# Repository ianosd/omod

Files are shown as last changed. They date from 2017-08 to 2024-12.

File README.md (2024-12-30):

# omod - Open Source Motor Driver
A motor driver used to command two motors. It avoids the complications of an H-bridge
by using a relay to switch the command direction (at the cost of making switching slower).
Checkout [the schematic pdf](schematic.pdf) for a quick impression.
You need KiCad to open the project files.

Here is a picture of the PCB layout:
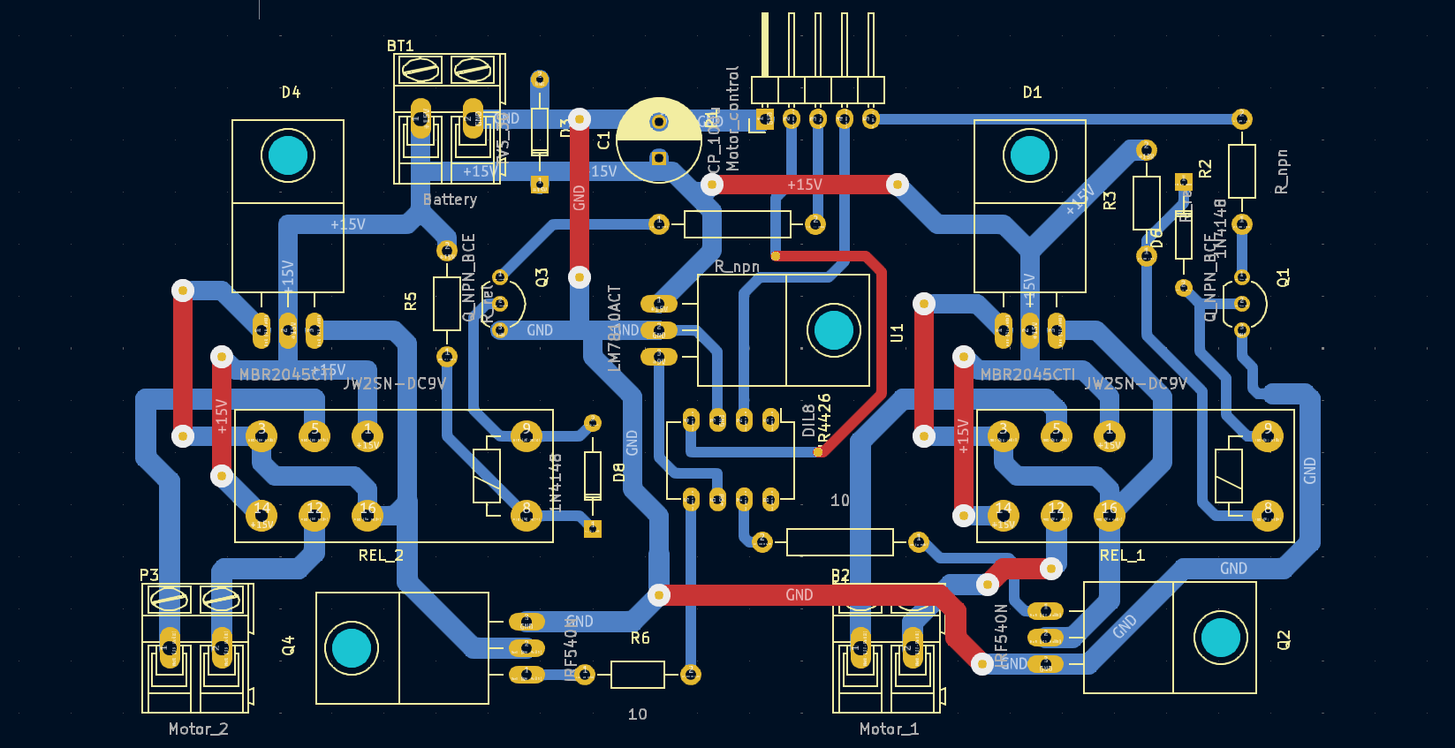
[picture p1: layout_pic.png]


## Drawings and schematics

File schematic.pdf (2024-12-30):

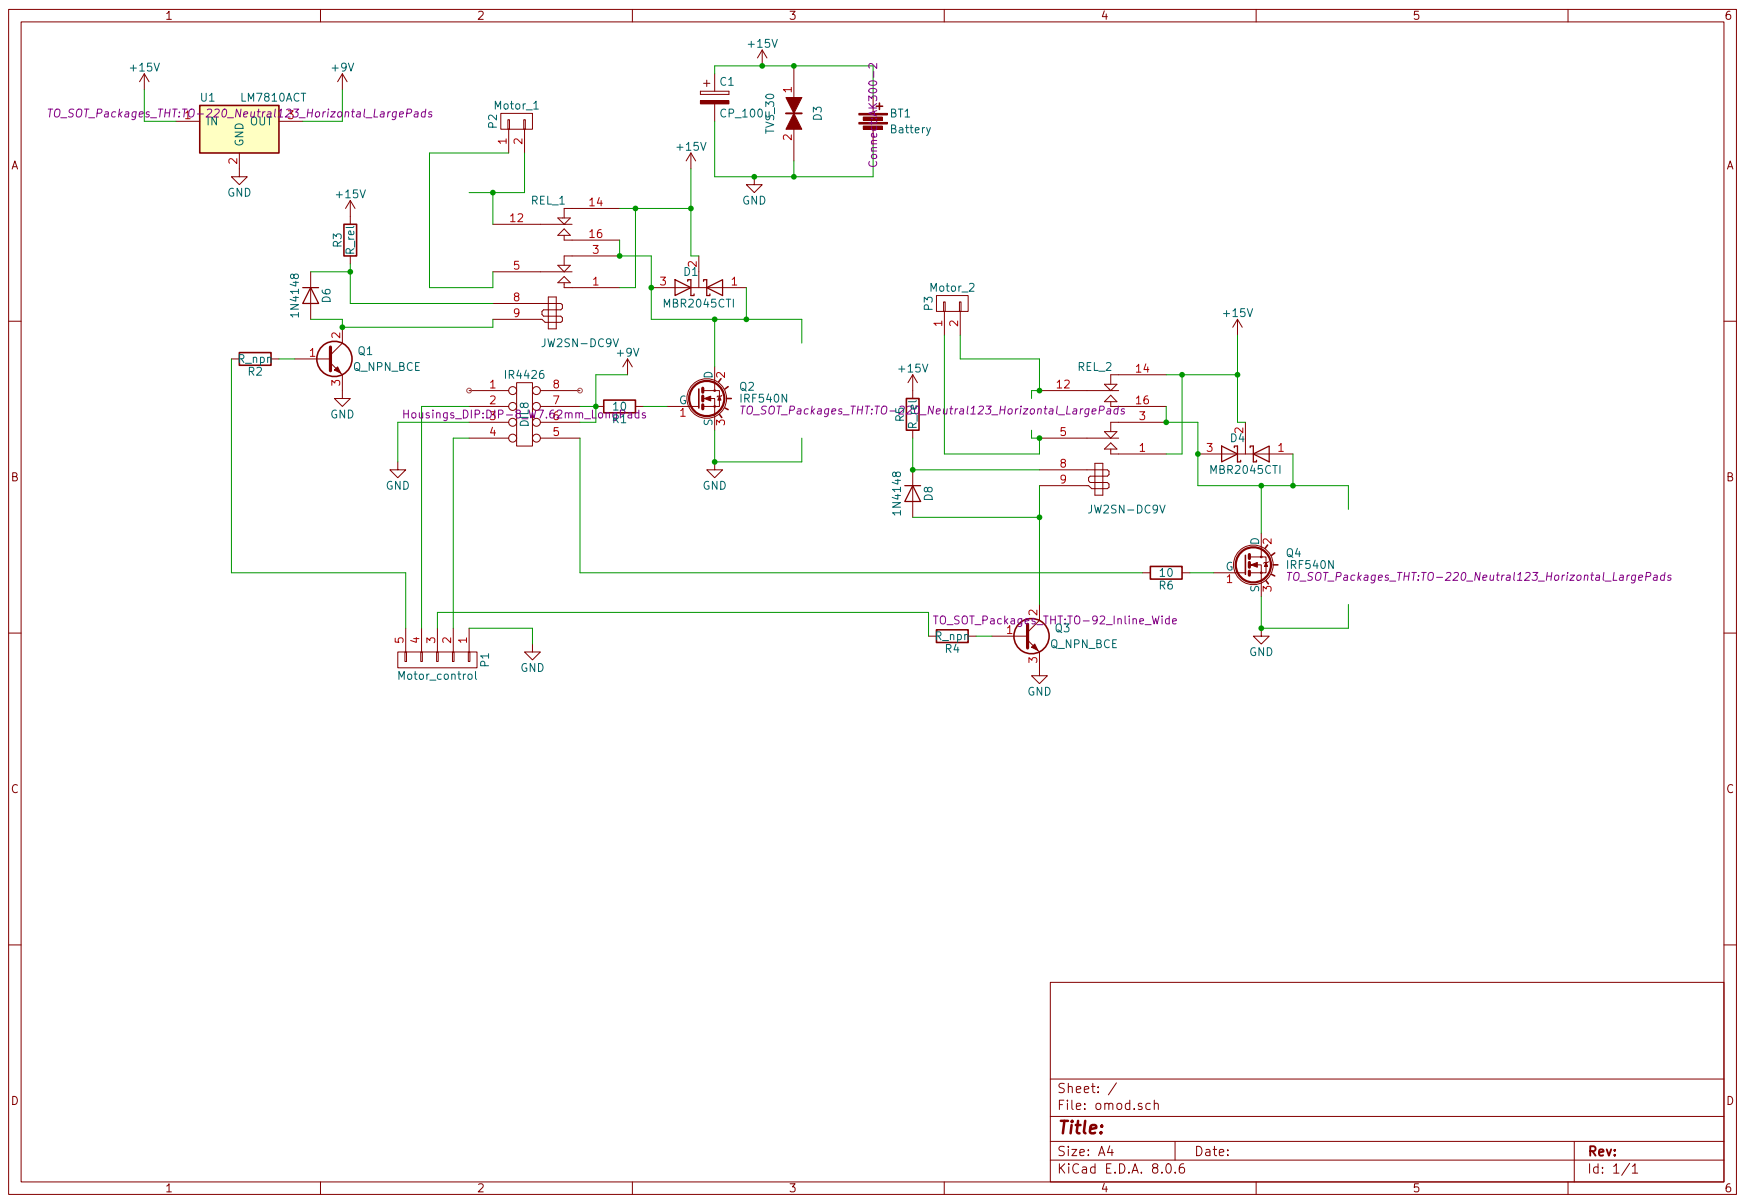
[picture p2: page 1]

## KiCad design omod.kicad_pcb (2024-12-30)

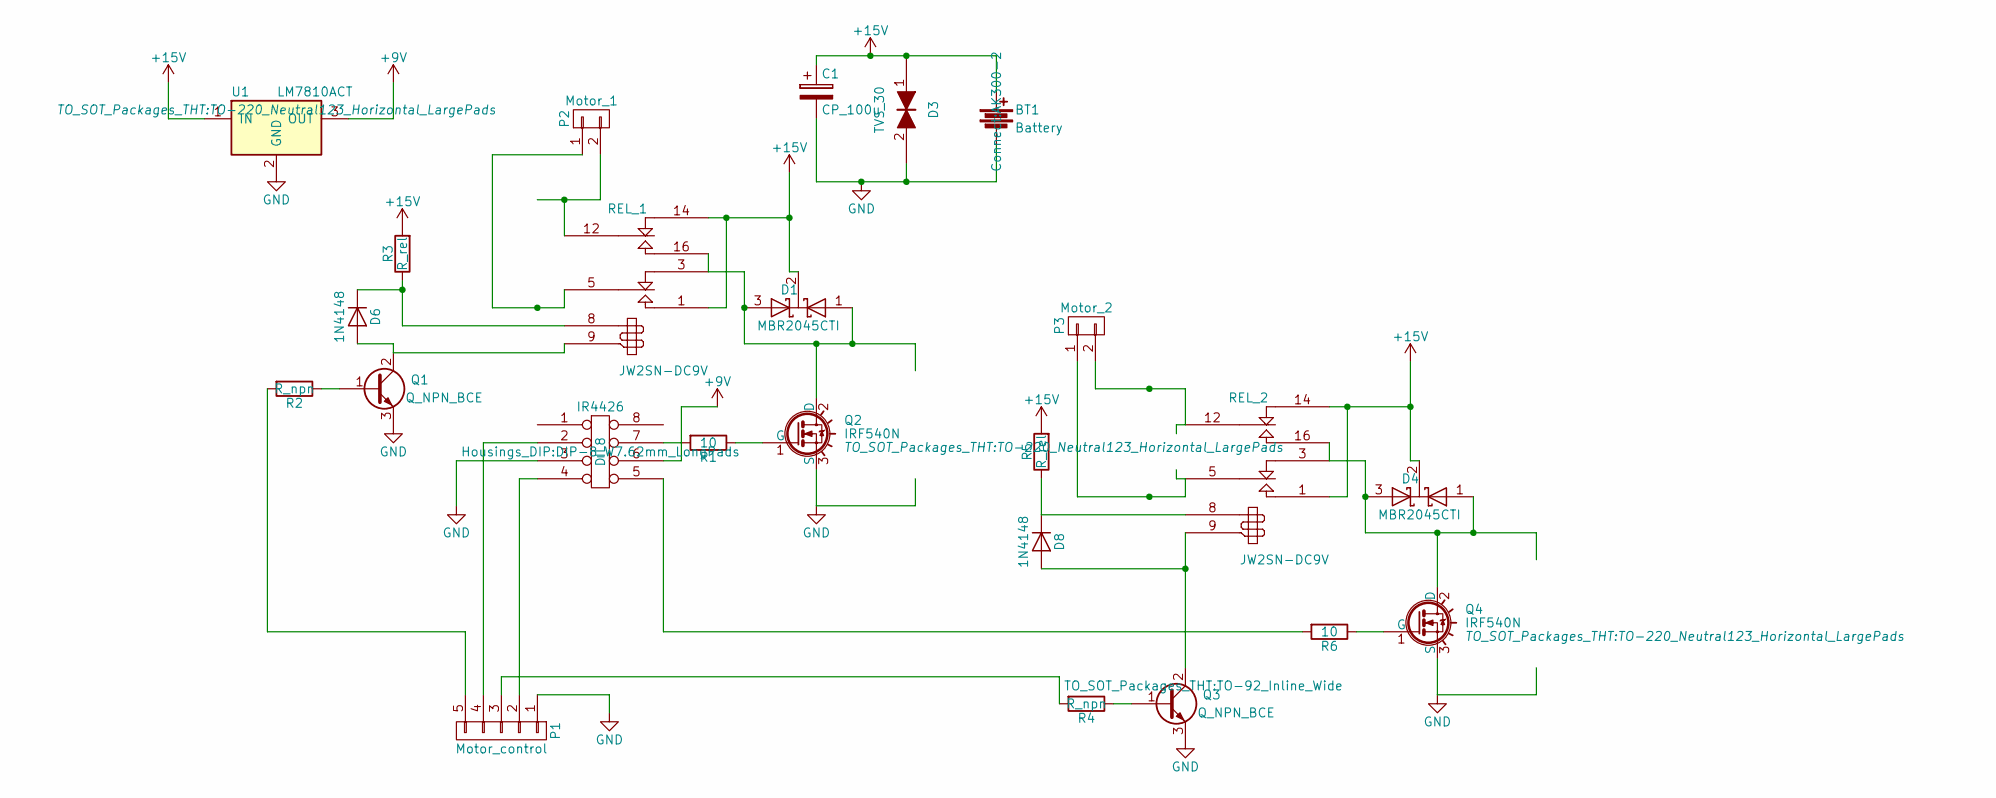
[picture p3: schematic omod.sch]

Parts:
BT1: Battery; AK300-2
C1: CP_100u; C_Radial_D8_L11.5_P3.5
D1, D4: MBR2045CTI; TO-220_Neutral123_Horizontal_LargePads
D3: TVS_30; Diode_DO-35_SOD27_Horizontal_RM10
D6, D8: 1N4148; Diode_DO-35_SOD27_Horizontal_RM10
IR4426: DIL8; DIP-8_W7.62mm_LongPads
P1: Motor_control; Pin_Header_Angled_1x05
P2: Motor_1; AK300-2
P3: Motor_2; AK300-2
Q1, Q3: Q_NPN_BCE; TO-92_Inline_Wide
Q2, Q4: IRF540N; TO-220_Neutral123_Horizontal_LargePads
R1: 10; Resistor_Horizontal_RM15mm
R2: R_npn; Resistor_Horizontal_RM10mm
R3, R5: R_rel; Resistor_Horizontal_RM10mm
R4: R_npn; Resistor_Horizontal_RM20mm
R6: 10; Resistor_Horizontal_RM10mm
REL_1, REL_2: JW2SN-DC9V; Relay_DPDT_Schrack-RT2_RM5mm_mine
U1: LM7810ACT; TO-220_Neutral123_Horizontal_LargePads

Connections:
+9V: IR4426.6 (Vs), U1.3 (OUT)
+15V: BT1.1, C1.1, D1.2 (K), D3.1, D4.2 (K), R3.2, R5.2, REL_1.1 (T1), REL_1.14 (R2), REL_2.1 (T1), REL_2.14 (R2), U1.1 (IN)
GND: BT1.2, C1.2, D3.2, IR4426.3 (GND), P1.1, Q1.3 (E), Q2.3 (S), Q3.3 (E), Q4.3 (S), U1.2 (GND)
unnamed: D1.1 (A), D1.3 (A), Q2.2 (D), REL_1.3 (R1), REL_1.16 (T2)
unnamed: D4.1 (A), D4.3 (A), Q4.2 (D), REL_2.3 (R1), REL_2.16 (T2)
unnamed: D6.1 (K), R3.1, REL_1.8
unnamed: D6.2 (A), Q1.2 (C), REL_1.9
unnamed: P2.2, REL_1.12 (C2)
unnamed: P2.1, REL_1.5 (C1)
unnamed: D8.1 (K), R5.1, REL_2.8
unnamed: D8.2 (A), Q3.2 (C), REL_2.9
unnamed: P3.2, REL_2.12 (C2)
unnamed: P3.1, REL_2.5 (C1)
unnamed: IR4426.2 (INA), P1.4
unnamed: IR4426.4 (INB), P1.2
unnamed: IR4426.5 (OUTB), R6.2
unnamed: IR4426.7 (OUTA), R1.2
unnamed: P1.3, R4.2
unnamed: P1.5, R2.2
unnamed: Q1.1 (B), R2.1
unnamed: Q2.1 (G), R1.1
unnamed: Q3.1 (B), R4.1
unnamed: Q4.1 (G), R6.1

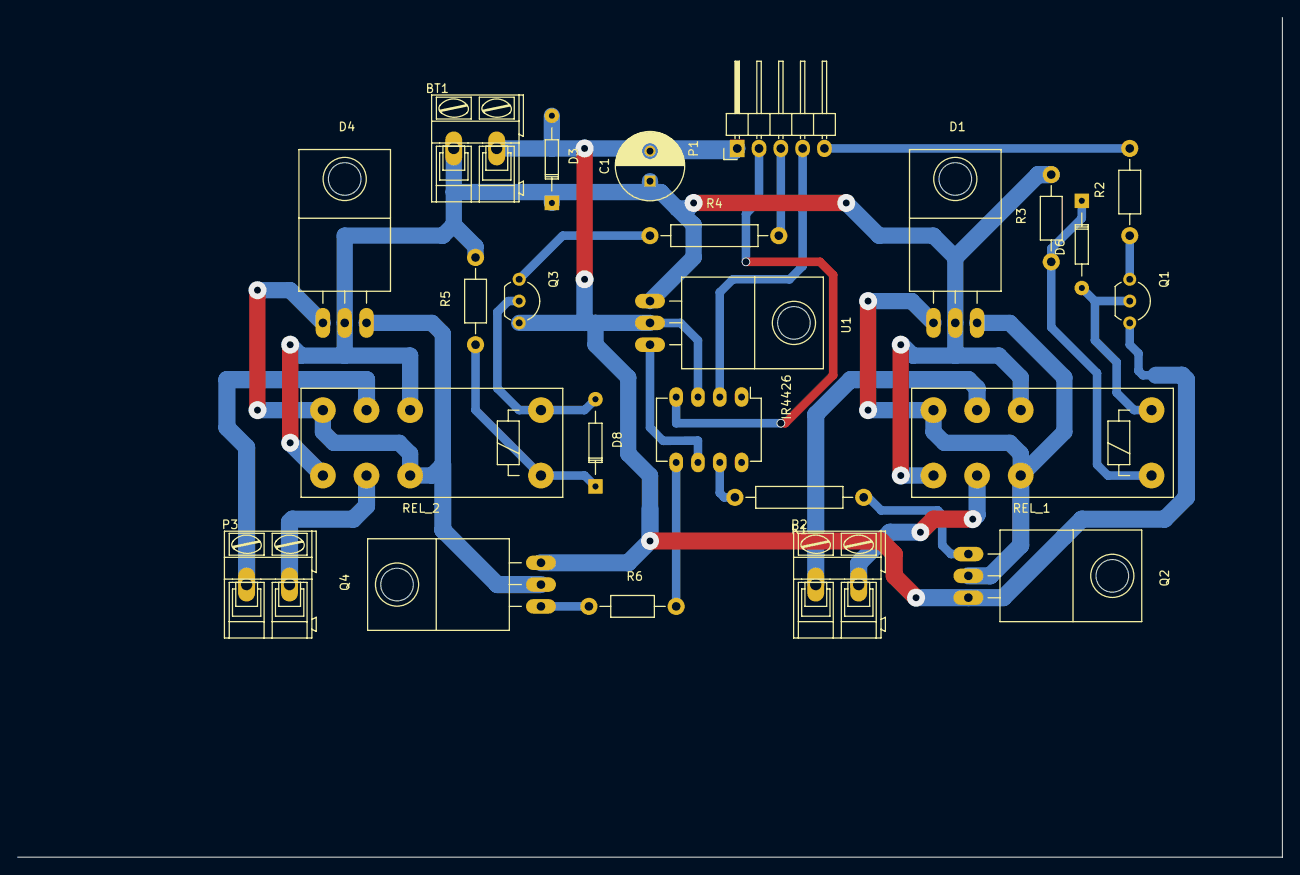
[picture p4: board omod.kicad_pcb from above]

Board: 2 copper layers, 147.3 x 97.8 mm, 24 parts (0 on the bottom side), 23 nets.

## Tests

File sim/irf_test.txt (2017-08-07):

.include irf540.txt

Xirf m_0 g 0 irf540
vg g 0 PULSE(0 5 0.04ms 0.01ms 0.01ms 0.14ms 0.2ms)
*Rl 1 d 200ohm
*Cl 1 d 1u

vdd m_1 0 15V

d1 d_end m_1 mod1
.model mod1 D
* MOTOR VOLTAGE
RA  m_1   m_2   0.5
LA  m_2   m_3   0.0015
H_EMF   m_3 m_4 VSENSE2 0.05
VSENSE1 m_4   m_0   DC 0V
*
* MOTOR TORQUE BASED ON INERTIA AND FRICTION
H_TORQ  m_6 0 VSENSE1 0.05
LJ  m_6   m_7   0.00025
RB  m_7   m_8   0.0001
VSENSE2 m_8   0   DC  0V

VSENSE_D1 m_0 d_end DC 0V

.tran 0.01ms 1s
.plot i(VSENSE1)
.plot v(m1, m0) v(g)
.plot i(VSENSE2)
.end

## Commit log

2017-07-24 old files added
    [omod.kicad_pcb, omod.sch]
2017-08-07 ok simulation and removed TVS
    [omod.kicad_pcb, omod.sch]
2017-08-07 before new pcb
    [omod.kicad_pcb]
2024-12-30 Improve README
    [omod.kicad_pcb]
